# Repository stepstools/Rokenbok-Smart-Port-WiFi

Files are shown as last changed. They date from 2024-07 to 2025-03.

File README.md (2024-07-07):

# Rokenbok Smart Port WiFi Adapter

An ESP32-S3 based system for communicating with the Rokenbok first generation command deck's "Smart Port" over WiFi.

## For More Information

Join the Rokenbok Discord server and check out the "roktronics-projects" channel for more info! - [Invite Link](https://discord.gg/neh6QHN)

## Authors

  - **Stepstools** - *Hardware Design and Firmware Developer* -
    [stepstools](https://github.com/stepstools)

See also the list of
[contributors](https://github.com/stepstools/Rokenbok-Smart-Port-WiFi/contributors)
who participated in this project.

## Acknowledgments

  - OTA Update Code Shamelessly Stolen From: https://github.com/Jeija/esp32-softap-ota/tree/master/main

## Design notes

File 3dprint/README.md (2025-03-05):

## 3D printable case FreeCAD source file and STLs for the SmartPort adapter

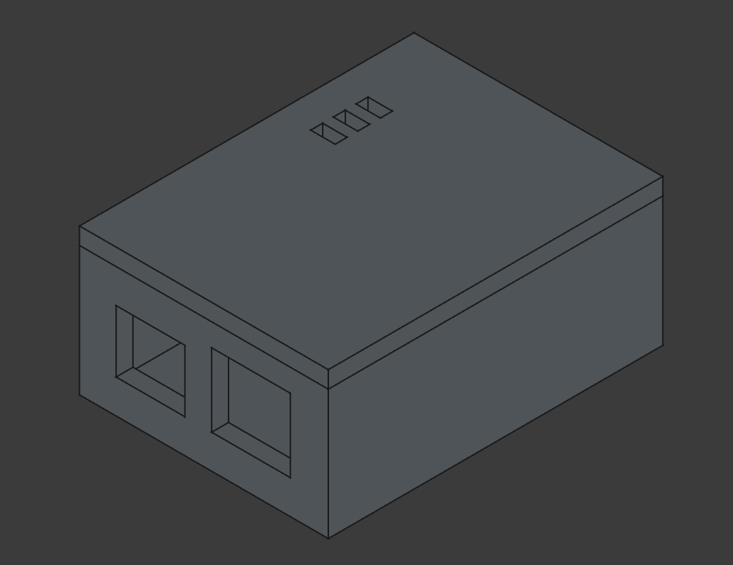
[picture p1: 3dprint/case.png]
Image of case


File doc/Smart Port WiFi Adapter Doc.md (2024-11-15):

# Rokenbok Smart Port WiFi Adapter Documentation

## Required Equipment

 1. Rokenbok WiFi Smart Port Adapter (SPA)
 2. USB A Male to USB B Male Cable (Printer Cable)
 3. Male to Male Mini-DIN-6 Cable (PS/2 Keyboard/Mouse Cable)

## Getting Started

 1. Power up the adapter by connecting it to a USB power source using the USB A to USB B cable.  You will see the red "PWR" LED illuminate.
 2. The blue "WIFI" LED on the device will begin blinking slowly.  This indicates that the device is in the WiFi provisioning mode and is functioning as a wireless access point.
 3. Using a WiFi enabled device, connect to the "Smart-Port-Provisioning" network.  The password is also "Smart-Port-Provisioning".
 4. Using a web browser, navigate to "1.2.3.4" to access the adapter's provisioning web server.  Follow the instructions on the page to input the SSID, password, and static IP information for your local network.
	 - WARNING: DO NOT set your admin password to a password you use for anything else.  This password is sent over the internet unencrypted if you use it later!  Safe enough for this little toy, but don't compromise your important passwords!
	 - Note: The IP address information is required to set up a known "static IP" address for your adapter.  This way your router's DHCP server won't change the adapter's IP and leave you unable to connect.
 5. After double checking all of your info, click the "Submit" button.  You will see the device restart.  If the WiFi LED goes solid blue, this means that it has successfully connected to your network.
	 - If the WiFi LED rapidbly blinks this means that it cannot connect to your network.  It will eventually clear your inputted credentials, reboot, and then re-enter provisioning mode.  You can also hold the reset button to re-enter provisioning mode at any time.  Double check your WiFi credentials and try again.
 6. Now connect the adapter to your Gen 1 Rokenbok RC command deck Smart Port using the male to male mini-DIN-6 cable.  It is best to do this while the command deck is off.
 7. Power up the command deck and the "SP" (Smart Port) LED on your adapter should turn green.
	 - If the SP LED does not illuminate, check your connection.  Excessively long cables (greater than 6 feet) may not work.
 8. On a device connected to your network (WiFi or ethernet), open a web browser and navigate to the static IP address that you selected.  You are now ready to use the device!
 9. You can control Rokenbok vehicles using either your keyboard or a standard layout gamepad.  Non standard gamepads will require additional software to emulate a standard gamepad.  See the "Help" page for more information about keyboard controls.  Gamepads should be automatically detected when you press a button.  The controls are identical to normal Rokenbok, except that start and select are used to change your vehicle selection.

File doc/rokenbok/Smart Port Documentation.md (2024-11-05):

# Rokenbok Smart Port Documentation

## Introduction

The first generation Rokenbok RC command deck featured an expansion port known as the “Smart Port.” Patent documents indicate that the company had intended to develop peripherals capable of interfacing through the port. Unfortunately these plans never materialized and the port was removed from subsequent generations of the RC command deck. More than two decades later the functionality of the port is now understood and peripherals have been develop to interface with the command deck.

## Smart Port Basic Functionality

The command deck actually has four virtual controllers in addition to the four physical controllers that can be plugged into the command deck. The basic purpose of the Smart Port is to manipulate these four virtual controllers. The microcontroller onboard the command deck stores the current vehicle selection value and button states for each of the eight controllers. An external peripheral can use the smart port to manipulate these values directly. As such, the smart port can actually override the physical controllers and manipulate all eight controllers. Additionally, Rokenbok had plans to create controllers that could select up to 16 vehicles. While this controller never materialized, the functionality existed on the command deck microcontroller and can be exploited by the smart port.

## The Smart Port Connector

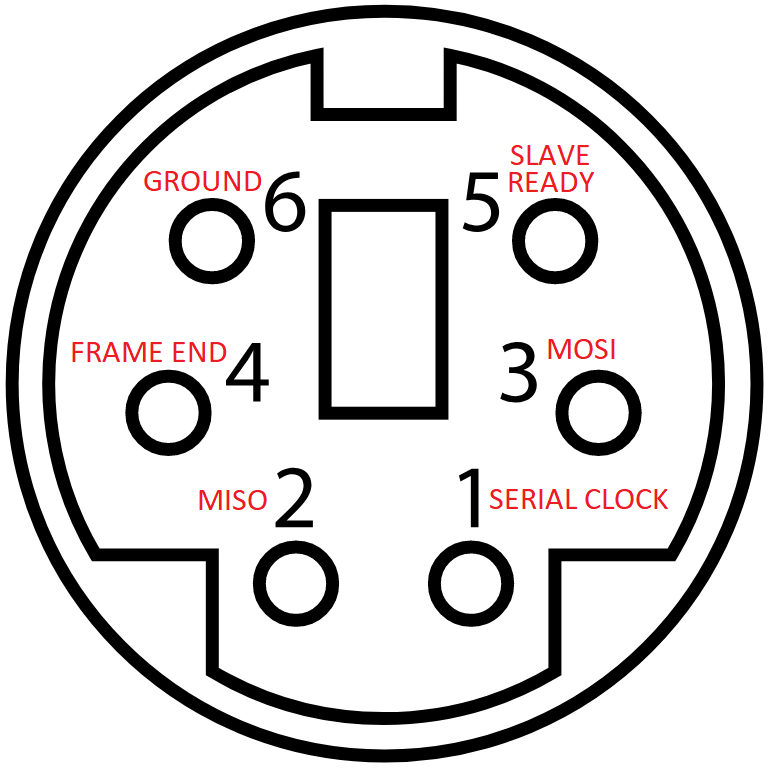
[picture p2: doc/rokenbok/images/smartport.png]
Smartport diagram


The Smart Port connector on the command deck closely resembles the PS/2 connector found on older mice and keyboards. While the connector is the same (female Mini DIN-6), the pinouts and communication protocols are entirely different. The protocol is similar to SPI but with two extra pins. In the serial communication the command deck functions as the master and the peripheral is the slave. Pin 1 is the serial clock provided by the command deck. Pin 2 is the Master In Slave Out data line provided by the peripheral. Pin 3 is the Master Out Slave In data line provided by the command deck. Pins 1, 2, and 3 are all 5V and active high. Pin 4 is known as the “frame end” pin. It is normally driven high at 12V by the command deck, but is pulled low at the end of each byte transmission by the command deck. It’s really not necessary in the serial communication – normal SPI serial communication does not use this. The slave should know when all 8 bits have been sent because of the clock. The reason why Rokenbok made this line 12V was to provide the peripheral with a source of power. The line is only pulled low less than 5% of the time, so a capacitor can be used to smooth that dip to provide continuous power to the peripheral through a regulator. Pin 5 is the “slave ready” pin. Again, most SPI communication protocols don’t use something like this. However, this line is required to make the connection work. The command deck weakly pulls the line up to 5V. When the peripheral is ready to receive the next byte it simply drives the line low. Once it has received the byte it sets the line back to high while it processes the new data. Pin 6 is simply a common ground between the master and slave.

## Serial Communication

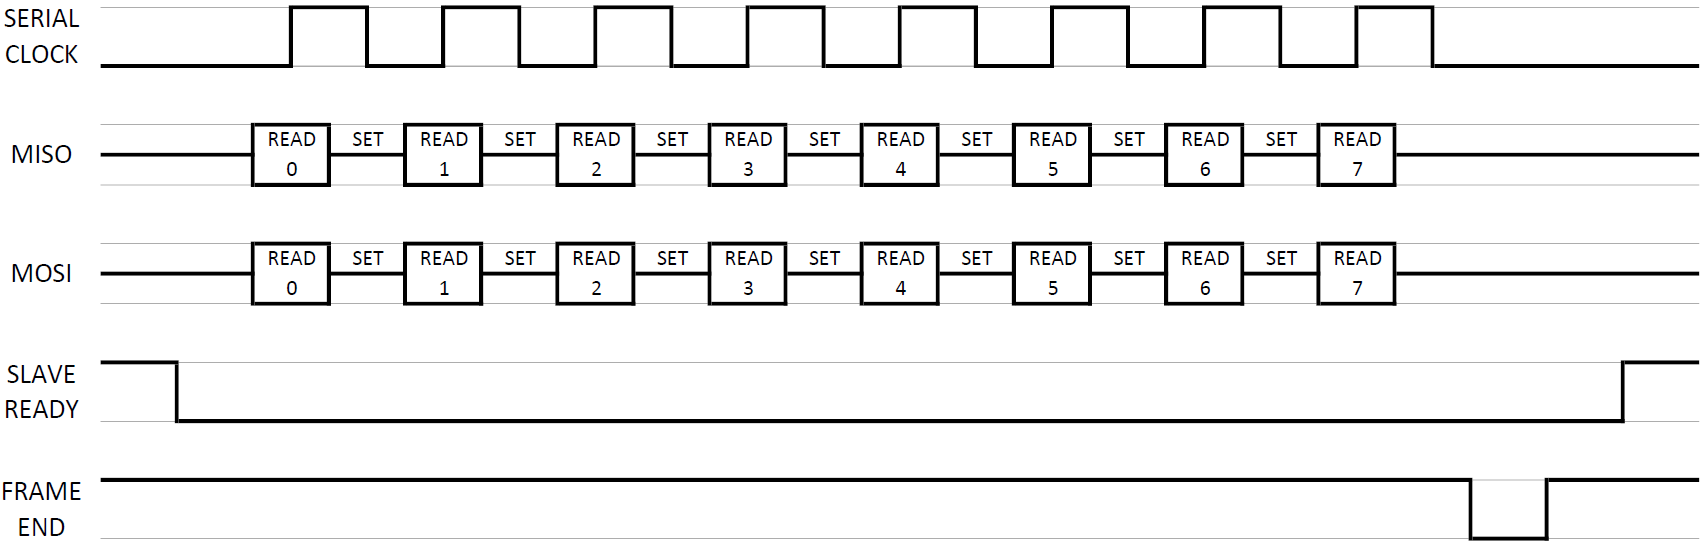
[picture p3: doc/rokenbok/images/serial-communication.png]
Serial communication


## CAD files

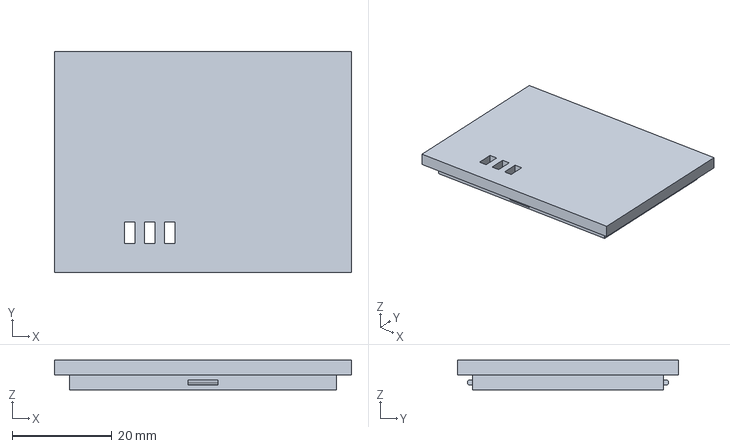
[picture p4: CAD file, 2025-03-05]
3dprint/smartportcase.FCStd
59.5 x 44.3 x 6.00 mm

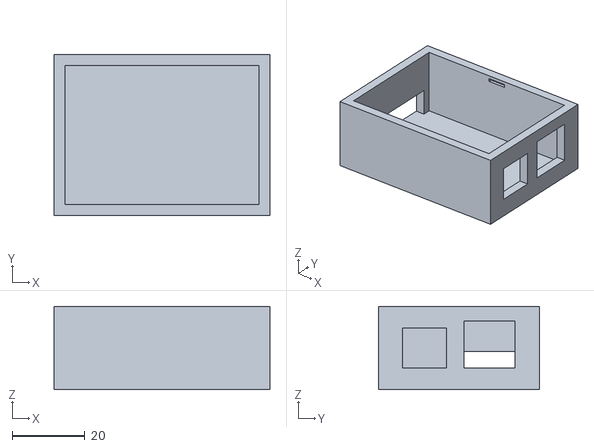
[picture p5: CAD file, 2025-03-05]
3dprint/body.stl
59.5 x 44.2 x 23.0

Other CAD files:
3dprint/lid.stl

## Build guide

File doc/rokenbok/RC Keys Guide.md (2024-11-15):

# Rokenbok RC Select Keys

## Overview

There are three main components of the selector keys used with the radio controlled Rokenbok system:

1. The LED and metal contacts on the side of the key.
    - Current flows from one contact, through the LED (emitting some photons along the way), and back to ground at the other contact.

2. The two central ridges on the back of the key.
    - The metal bars connecting these ridges are used as a sort of switch that closes the connection between the corresponding metal buttons inside the key socket on the vehicle. This is how the machine knows when a key has been inserted, removed, or pressed down to wake the vehicle.

3. The remaining four ridges (or lack thereof) on the back of the key.
    - These ridges are used as binary code to identify which key has been inserted into the vehicle. This is where the magic happens…

## Binary and Rokenbok

If you know absolutely nothing about binary numbering, I recommend you watch some videos online. You’ll be able to pick it up pretty quickly. As mentioned before, the 4 outer ridges on the RC keys are each one bit. This means that there are 2<sup>4</sup> possible combinations for the ridges and therefore 16 unique control keys. In case you were curious, 4 bits is half of a byte and is therefore referred to as a _nibble_. For reference, here are the equivalent binary, hex, and decimal values for each possible number in a nibble:

| **Binary** | **Hexadecimal** | **Decimal** | **Key Number** |
| --- | --- | --- | --- |
| 0000 | 0 | 0 | 1 |
| 0001 | 1 | 1 | 2 |
| 0010 | 2 | 2 | 3 |
| 0011 | 3 | 3 | 4 |
| 0100 | 4 | 4 | 5 |
| 0101 | 5 | 5 | 6 |
| 0110 | 6 | 6 | 7 |
| 0111 | 7 | 7 | 8 |
| 1000 | 8 | 8 | 9 |
| 1001 | 9 | 9 | 10  |
| 1010 | A | 10  | 11  |
| 1011 | B | 11  | 12  |
| 1100 | C | 12  | 13  |
| 1101 | D | 13  | 14  |
| 1110 | E | 14  | 15  |
| 1111 | F | 15  | No Select |

Okay, so what do nibbles have to do with Rokenbok? I’m glad you asked. When you insert a key into the socket of a vehicle, the 4 outer ridges either depress one of the metal switches or they don’t. If there is a ridge, the switch is depressed. If there isn’t a ridge, the switch is not depressed. Rokenbok decided to be a bit counterintuitive with how they set up this numbering system, so it takes some explaining:

- Because most people don’t start counting at zero, the actual key number is the binary number plus one (this can be seen in the previous table).

  - Also, one value needed to be assigned as a “no selection” value, so 1111 was chosen for this. If the smart port is used to force the selection of a physical controller to decimal number 15, the selection LEDs will spin in a circle as if the controller was asleep.

- The presence of a ridge (and therefore a pressed switch) is a binary zero. The absence of a ridge (and therefore an unpressed switch) is a binary one.

  - This is clearly seen on the number 1 key, which has all four ridges present, therefore corresponding to binary number 0000.

- The ridges are not in any specific order. The pictures below show the order of the ridges starting from bit 0 (all the way right in a nibble) to bit 3 (all the way left in a nibble).

  - This can be clearly seen in the number 8 key, which only has ridge 3 remaining, corresponding to binary number 0111.

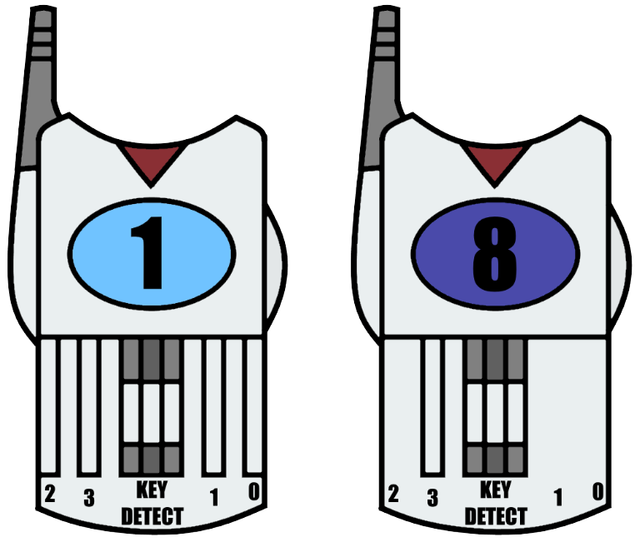
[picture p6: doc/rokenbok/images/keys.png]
Rokenbok key diagram


## Controlling More Than Eight Vehicles

Rokenbok decided to be boring and only use 8 of the 16 possible keys. They actually described potentially making controllers capable of selecting 16 vehicles in their patent requests, but they never got around to doing it. However, the smart port is more than capable of controlling these extra vehicles! Unfortunately, number 16 is unavailable due to its use as the “no select” code, but we can still get numbers 9-15! If you’ve been following along, you’ll know that control keys 1-8 all have ridge three present. Now, if we remove that ridge, suddenly bit number 3 changes from a zero to a one. A one in binary position three is equal to 8, so you’ve just added 8 to the value of the key! Number 1 becomes 9, 2 becomes 10, etc. This checks out with the table above if you flip the leftmost bit of any number. Don’t forget that there’s no need to hack up your number 8 key since 16 isn’t a valid selection.

~~Caveat: I haven’t actually done this. However, I had a friend help me and depress the switch for bit zero on a vehicle using a small screwdriver while I used a piece of wire to simulate the central ridges turning on the vehicle. I was successfully able to control the vehicle as key number 15 (binary 1110, only ridge zero present). It might be possible that only certain vehicles work with this hack. My worst case scenario guess is that only older vehicles work with this. It’s possible that newer vehicles lost this functionality once Rokenbok ditched the smart port and decided not to make 16 selection controllers. Of course, my best case scenario guess is that they all work! Only one way to find out…~~

Update: Multiple people have successfully created keys 9-15 by physically removing the third ridge from keys 1-7.  Key 8 cannot be turned into key 16.

Guide By: Stepstools, the Smart Port Dude

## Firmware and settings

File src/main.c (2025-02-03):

// ASCII Art: https://www.patorjk.com/software/taag/ ("Big" Font)
// OTA Update Code Shamelessly Stolen From: https://github.com/Jeija/esp32-softap-ota/tree/master/main

#include <stdio.h>
#include <string.h>
#include "freertos/FreeRTOS.h"
#include "freertos/task.h"
#include "freertos/event_groups.h"
#include "nvs_flash.h"
#include <esp_system.h>
#include "esp_wifi.h"
#include "esp_event.h"
#include "esp_log.h"
#include "esp_http_server.h"
#include "esp_http_client.h"
#include "esp_netif.h"
#include "lwip/sockets.h"
#include "driver/gpio.h"
#include "driver/gpio_filter.h"
#include "driver/spi_slave.h"
#include "esp_timer.h"
#include "esp_ota_ops.h"

#define MIN(a, b) (((a) < (b)) ? (a) : (b))
#define MAX(a, b) (((a) > (b)) ? (a) : (b))

// OTA Firmware Update URL
#define OTA_URL "https://raw.githubusercontent.com/stepstools/Rokenbok-Smart-Port-WiFi/refs/heads/main/firmware/ota_firmware.bin"

// WiFi Defines
#define AP_SSID "Smart-Port-Provisioning"
#define AP_PASSWORD "Smart-Port-Provisioning"
#define MAX_WIFI_SSID_LEN 32
#define MAX_WIFI_PASSWORD_LEN 64
#define WIFI_CONNECT_ATTEMPTS 20

// Smart Port Master Bytes
#define NULL_CMD 0x00
#define BCAST_TPADS 0xc0
#define BCAST_SELECT 0xC1
#define BCAST_END 0xC2
#define EDIT_TPADS 0xC3
#define EDIT_SELECT 0xC4
#define EDIT_END 0xC5
#define PRESYNC 0xC6
#define MASTER_SYNC 0xC7
#define READ_ATTRIB 0xC8
#define MASTER_NO_INS 0xC9
#define MASTER_ASK_INS 0xCA
#define READ_REPLY 0xCB
#define READ_NO_SEL_TIMEOUT 0xCC
#define NO_RADIO_PKT 0xCD
#define HAVE_RADIO_PKT 0xCE

// Smart Port Slave Bytes
#define NULL_CMD 0x00
#define VERIFY_EDIT 0x80
#define SLAVE_SYNC 0x81
#define SLAVE_NO_INS 0x82
#define SLAVE_WAIT_INS 0x83
#define PACKET_INJECT_ATTRIB_BYTE 0x2D // Packet Injection
#define ENABLE_ATTRIB_BYTE 0x0D // No Packet Injection
#define DISABLE_ATTRIB_BYTE 0x00
#define NO_SEL_TIMEOUT 0x00 // 1 = Controller Never Times Out, 0 = Normal V4|V3|V2|V1|P4|P3|P2|P1

// Series Logic Defines
#define NO_SERIES 0
#define SYNC_SERIES 1
#define EDIT_TPADS_SERIES 2
#define EDIT_SELECT_SERIES 3
#define PKT_INJECT_SERIES 4

// GPIO Defines
#define GPIO_RESET 0
#define GPIO_MOSI 11
#define GPIO_MISO 13
#define GPIO_SCLK 12
#define GPIO_FE 9
#define GPIO_SR 21
#define GPIO_WIFI_LED 18
#define GPIO_SP_LED 17

//  __      __     _____  _____          ____  _      ______  _____   //
//  \ \    / /\   |  __ \|_   _|   /\   |  _ \| |    |  ____|/ ____|  //
//   \ \  / /  \  | |__) | | |    /  \  | |_) | |    | |__  | (___    //
//    \ \/ / /\ \ |  _  /  | |   / /\ \ |  _ <| |    |  __|  \___ \   //
//     \  / ____ \| | \ \ _| |_ / ____ \| |_) | |____| |____ ____) |  //
//      \/_/    \_\_|  \_\_____/_/    \_\____/|______|______|_____/   //

// Global Variables
char nvs_admin_password[33] = "NULL";
char nvs_vehicle_names[15][21] = {"No Data", "No Data", "No Data", "No Data", "No Data", "No Data", "No Data", "No Data", "No Data", "No Data", "No Data", "No Data", "No Data", "No Data", "No Data"};
char control_key_user_names[256][17] = {0};

// Rokenbok Control Logic Variables
uint8_t timeouts[12] = {false, false, false, false, false, false, false, false, false, false, false, false}; // V1, V2, V3, V4, P1, P2, P3, P4, D1, D2, D3, D4
uint8_t enable_control[12] = {false, false, false, false, false, false, false, false, false, false, false, false}; // V1, V2, V3, V4, P1, P2, P3, P4, D1, D2, D3, D4 // FALSE = Normal, TRUE = SP Controlled
//uint8_t control_keys[12] = {0x19, 0x20, 0x30, 0x40, 0x50, 0x60, 0x70, 0x80, 0x00, 0x00, 0x00, 0x00}; // V1, V2, V3, V4, P1, P2, P3, P4, D1, D2, D3, D4
uint8_t control_keys[12] = {0x00, 0x00, 0x00, 0x00, 0x00, 0x00, 0x00, 0x00, 0x00, 0x00, 0x00, 0x00}; // V1, V2, V3, V4, P1, P2, P3, P4, D1, D2, D3, D4
uint8_t next_control_key = 2; // 0 = Unused, 1 = Physical Controller Plugged In

uint8_t next_dpi_index = 0;

uint8_t selects[12] = {0x0F, 0x0F, 0x0F, 0x0F, 0x0F, 0x0F, 0x0F, 0x0F, 0x0F, 0x0F, 0x0F, 0x0F}; // V1, V2, V3, V4, P1, P2, P3, P4, D1, D2, D3, D4

uint8_t share_mode = true;
uint8_t is16sel_mode = true;
uint8_t controller_timeout = 10;

uint8_t enabled_controllers = 0b11111111; // V4|V3|V2|V1|P4|P3|P2|P1 // 0 = Enabled, 1 = Disabled
uint8_t sp_a = 0x00;                      // V4|V3|V2|V1|P4|P3|P2|P1
uint8_t sp_b = 0x00;
uint8_t sp_x = 0x00;
uint8_t sp_y = 0x00;
uint8_t sp_up = 0x00;
uint8_t sp_down = 0x00;
uint8_t sp_right = 0x00;
uint8_t sp_left = 0x00;
uint8_t sp_rt = 0x00;
// uint8_t sp_sel_button = 0x00;
// uint8_t sp_lt = 0x00;
// uint8_t sp_share = 0x00;
// uint8_t sp_is16SEL = 0x00;
uint8_t sp_priority_byte = 0x00;

uint8_t dpi_a[4] = {false, false, false, false};
uint8_t dpi_b[4] = {false, false, false, false};
uint8_t dpi_x[4] = {false, false, false, false};
uint8_t dpi_y[4] = {false, false, false, false};
uint8_t dpi_up[4] = {false, false, false, false};
uint8_t dpi_down[4] = {false, false, false, false};
uint8_t dpi_left[4] = {false, false, false, false};
uint8_t dpi_right[4] = {false, false, false, false};
uint8_t dpi_rt[4] = {false, false, false, false};

uint8_t sp_status = 0;

uint8_t spi_current_series = 0;
uint8_t spi_series_count = 0;

// Variables and Structs for WiFi Event Management
EventGroupHandle_t wifi_event_group;
uint8_t WIFI_CONNECTED_BIT = BIT0;
uint8_t connection_attempts = 0;
uint8_t wifi_led_status = false;

// Timer Handle Definitions
esp_timer_handle_t sync_timer;
esp_timer_handle_t timeout_timer;
esp_timer_handle_t post_timeout_timer;
esp_timer_handle_t reset_button_timer;
esp_timer_handle_t wifi_led_timer;

//   _    _ ______ _      _____  ______ _____    //
//  | |  | |  ____| |    |  __ \|  ____|  __ \   //
//  | |__| | |__  | |    | |__) | |__  | |__) |  //
//  |  __  |  __| | |    |  ___/|  __| |  _  /   //
//  | |  | | |____| |____| |    | |____| | \ \   //
//  |_|  |_|______|______|_|    |______|_|  \_\  //

/// @brief Converts all + to spaces and converts percent encoded values within a string.
/// @param string String to process.
void convert_percent_encoded(char *string) {
    char *src = string;
    char *dst = string;
    while (*src) {
        if (*src == '+') {
            *dst++ = ' '; // Convert '+' to space
            src++;
        } else if (src[0] == '%' && isxdigit((unsigned char)src[1]) && isxdigit((unsigned char)src[2])) {
            int value;
            sscanf(src + 1, "%2x", &value); // Convert hex digits to a character
            *dst++ = (char)value;
            src += 3; // Move past "%XX"
        } else {
            *dst++ = *src++; // Copy regular characters
        }
    }
    *dst = '\0'; // Null-terminate the result string
}

/// @brief Helper function to determine if an array contains a value.
/// @param array The array to be checked.
/// @param size The size of the array.
/// @param value The value being looked for.
/// @return true or false boolean value.
bool contains(uint8_t array[], size_t size, uint8_t value)
{
    for (size_t i = 0; i < size; i++)
    {
        if (array[i] == value)
        {
            return true;
        }
    }
    return false;
}

//  __          ________ ____   _____ ______ _______      ________ _____    //
//  \ \        / /  ____|  _ \ / ____|  ____|  __ \ \    / /  ____|  __ \   //
//   \ \  /\  / /| |__  | |_) | (___ | |__  | |__) \ \  / /| |__  | |__) |  //
//    \ \/  \/ / |  __| |  _ < \___ \|  __| |  _  / \ \/ / |  __| |  _  /   //
//     \  /\  /  | |____| |_) |____) | |____| | \ \  \  /  | |____| | \ \   //
//      \/  \/   |______|____/|_____/|______|_|  \_\  \/   |______|_|  \_\  //

/// @brief HTTP Client Event Handler
/// @param evt Event to handle.
/// @return Error Code
esp_err_t http_client_event_handler(esp_http_client_event_t *evt) {
    // switch(evt->event_id) {
    //     case HTTP_EVENT_ERROR:
    //         ESP_LOGI("HTTP CLIENT", "HTTP_EVENT_ERROR");
    //         break;
    //     case HTTP_EVENT_ON_CONNECTED:
    //         ESP_LOGI("HTTP CLIENT", "HTTP_EVENT_ON_CONNECTED");
    //         break;
    //     case HTTP_EVENT_HEADER_SENT:
    //         ESP_LOGI("HTTP CLIENT", "HTTP_EVENT_HEADER_SENT");
    //         break;
    //     case HTTP_EVENT_ON_HEADER:
    //         ESP_LOGI("HTTP CLIENT", "HTTP_EVENT_ON_HEADER, key=%s, value=%s", evt->header_key, evt->header_value);
    //         break;
    //     case HTTP_EVENT_ON_DATA:
    //         ESP_LOGI("HTTP CLIENT", "HTTP_EVENT_ON_DATA, len=%d", evt->data_len);
    //         break;
    //     case HTTP_EVENT_ON_FINISH:
    //         ESP_LOGI("HTTP CLIENT", "HTTP_EVENT_ON_FINISH");
    //         break;
    //     case HTTP_EVENT_DISCONNECTED:
    //         ESP_LOGI("HTTP CLIENT", "HTTP_EVENT_DISCONNECTED");
    //         break;
    //     case HTTP_EVENT_REDIRECT:
    //         ESP_LOGI("HTTP CLIENT", "HTTP_EVENT_REDIRECT");
    //         break;
    // }
    return ESP_OK;
}

/// @brief Interprets received control codes and assigns controllers to control keys.
/// @param control_code Specified Action Code (Press A, Unpress A, etc.)
/// @param control_key Control Key For the Source Gamepad/Keyboard/Mobile
/// @return void
static uint8_t IRAM_ATTR handle_control_bytes(uint8_t control_code, uint8_t control_key, uint8_t requested_vehicle)
{
    uint8_t controller_index = 255;
    for (uint8_t i = 0; i < 12; i++) // Search For Control Key In Virtual, Physical, and Direct Packet Injection (DPI)
    {
        if (control_keys[i] == control_key) // Control Key Found
        {
            controller_index = i;
            // ESP_LOGI("SP", "CONTROL KEY %i ALREADY ASSIGNED TO CONTROLLER %i", control_key, i);
            break;
        }
    }

    if (controller_index == 255) // Control Key Not Found
    {
        for (uint8_t i = 0; i < 12; i++) // Search For Unused Virtual or Physical Controller
        {
            if (control_keys[i] == 0) // Controller Not Currently Used
            {
                controller_index = i;
                control_keys[i] = control_key;
                enable_control[i] = true;
                if (controller_index < 8) // Only Do This Step For Virtual and Physical Controllers
                {
                    enabled_controllers &= ~(0b00000001 << ((i + 4) % 8));
                }
                // ESP_LOGI("SP", "CONTROL KEY %i NOW ASSIGNED TO CONTROLLER %i", control_key, i);
                break;
            }
        }
    }

    if (controller_index == 255) // No Empty Spots Available
    {
        //ESP_LOGI("SP", "NO AVAILABLE CONTROLLERS TO ASSIGN");
        return 0xFF;
    }

    timeouts[controller_index] = true; // Indicate That Controller Was Used During Timeout Cycle

    uint8_t select_changed = false;
    if (selects[controller_index] != requested_vehicle)
    { // If the requested vehicle is different from the stored value...
        select_changed = true;
        if ((share_mode) || (requested_vehicle == 15))
        { // Just give the assignment if share mode is on or no_select is requested.
            selects[controller_index] = requested_vehicle;
        }
        else
        { 
            uint8_t new_vehicle = requested_vehicle;
            uint8_t max_value = (is16sel_mode ? 14 : 7);
            
            if (new_vehicle == (selects[controller_index] + 1) % (max_value + 1))
            { // Detecting if the value was incremented.
                while (contains(selects, 8, new_vehicle)) {
                    new_vehicle = (new_vehicle + 1) % (max_value + 1);
                }
            }
            else //if (new_vehicle == (selects[controller_index] - 1 + max_value + 1) % (max_value + 1))
            { // Detecting if the value was decremented.
                while (contains(selects, 8, new_vehicle)) {
                    new_vehicle = (new_vehicle == 0) ? max_value : (new_vehicle - 1);
                }
            }
            selects[controller_index] = new_vehicle;
        }
    }

    if (controller_index < 8) // Virtual or Physical Controllers
    {
        uint8_t bitwise_index = (controller_index + 4) % 8; // Convert V1-4, P1-4 Array Index to V4|V3|V2|V1|P4|P3|P2|P1 Bitwise
        switch (control_code)
        {
        // PRESS CONTROL CODES
        case 0x00:
            sp_a |= (0b00000001 << bitwise_index);
            sp_priority_byte |= (0b00000001 << bitwise_index);
            break;

        case 0x01:
            sp_b |= (0b00000001 << bitwise_index);
            sp_priority_byte |= (0b00000001 << bitwise_index);
            break;

        case 0x02:
            sp_x |= (0b00000001 << bitwise_index);
            sp_priority_byte |= (0b00000001 << bitwise_index);
            break;

        case 0x03:
            sp_y |= (0b00000001 << bitwise_index);
            sp_priority_byte |= (0b00000001 << bitwise_index);
            break;

        case 0x04:
            sp_up |= (0b00000001 << bitwise_index);
            sp_priority_byte |= (0b00000001 << bitwise_index);
            break;

        case 0x05:
            sp_down |= (0b00000001 << bitwise_index);
            sp_priority_byte |= (0b00000001 << bitwise_index);
            break;

        case 0x06:
            sp_left |= (0b00000001 << bitwise_index);
            sp_priority_byte |= (0b00000001 << bitwise_index);
            break;

        case 0x07:
            sp_right |= (0b00000001 << bitwise_index);
            sp_priority_byte |= (0b00000001 << bitwise_index);
            break;

        case 0x08:
            sp_rt |= (0b00000001 << bitwise_index);
            sp_priority_byte |= (0b00000001 << bitwise_index);
            break;

        // UNPRESS CONTROL CODES
        case 0x10:
            sp_a &= ~(0b00000001 << bitwise_index);
            sp_priority_byte |= (0b00000001 << bitwise_index);
            break;

        case 0x11:
            sp_b &= ~(0b00000001 << bitwise_index);
            sp_priority_byte |= (0b00000001 << bitwise_index);
            break;

        case 0x12:
            sp_x &= ~(0b00000001 << bitwise_index);
            sp_priority_byte |= (0b00000001 << bitwise_index);
            break;

        case 0x13:
            sp_y &= ~(0b00000001 << bitwise_index);
            sp_priority_byte |= (0b00000001 << bitwise_index);
            break;

        case 0x14:
            sp_up &= ~(0b00000001 << bitwise_index);
            sp_priority_byte |= (0b00000001 << bitwise_index);
            break;

        case 0x15:
            sp_down &= ~(0b00000001 << bitwise_index);
            sp_priority_byte |= (0b00000001 << bitwise_index);
            break;

        case 0x16:
            sp_left &= ~(0b00000001 << bitwise_index);
            sp_priority_byte |= (0b00000001 << bitwise_index);
            break;

        case 0x17:
            sp_right &= ~(0b00000001 << bitwise_index);
            sp_priority_byte |= (0b00000001 << bitwise_index);
            break;

        case 0x18:
            sp_rt &= ~(0b00000001 << bitwise_index);
            sp_priority_byte |= (0b00000001 << bitwise_index);
            break;

        case 0x19: // Unpress All
            sp_a &= ~(0b00000001 << bitwise_index);
            sp_b &= ~(0b00000001 << bitwise_index);
            sp_x &= ~(0b00000001 << bitwise_index);
            sp_y &= ~(0b00000001 << bitwise_index);
            sp_up &= ~(0b00000001 << bitwise_index);
            sp_down &= ~(0b00000001 << bitwise_index);
            sp_left &= ~(0b00000001 << bitwise_index);
            sp_right &= ~(0b00000001 << bitwise_index);
            sp_rt &= ~(0b00000001 << bitwise_index);
            sp_priority_byte |= (0b00000001 << bitwise_index);
            break;

        case 0x1A: // Release Controller
            sp_a &= ~(0b00000001 << bitwise_index);
            sp_b &= ~(0b00000001 << bitwise_index);
            sp_x &= ~(0b00000001 << bitwise_index);
            sp_y &= ~(0b00000001 << bitwise_index);
            sp_up &= ~(0b00000001 << bitwise_index);
            sp_down &= ~(0b00000001 << bitwise_index);
            sp_left &= ~(0b00000001 << bitwise_index);
            sp_right &= ~(0b00000001 << bitwise_index);
            sp_rt &= ~(0b00000001 << bitwise_index);
            sp_priority_byte |= (0b00000001 << bitwise_index);

            selects[controller_index] = 15;
            select_changed = true;

            timeouts[controller_index] = false;
            control_keys[controller_index] = 0;

            esp_timer_start_once(post_timeout_timer, 0.1 * 1000000); // 0.1 Second Interval
            break;

        // UTILITY CONTROL CODES
        // case 0x40: // Soft Reset
        //     enable_control[0] = false;
        //     enable_control[1] = false;
        //     enable_control[2] = false;
        //     enable_control[3] = false;
        //     enable_control[4] = false;
        //     enable_control[5] = false;
        //     enable_control[6] = false;
        //     enable_control[7] = false;

        //     enabled_controllers = 0xFF;

        //     selects[0] = 0x0F;
        //     selects[1] = 0x0F;
        //     selects[2] = 0x0F;
        //     selects[3] = 0x0F;
        //     selects[4] = 0x0F;
        //     selects[5] = 0x0F;
        //     selects[6] = 0x0F;
        //     selects[7] = 0x0F;

        //     sp_a = 0x00;
        //     sp_b = 0x00;
        //     sp_x = 0x00;
        //     sp_y = 0x00;
        //     sp_up = 0x00;
        //     sp_down = 0x00;
        //     sp_right = 0x00;
        //     sp_left = 0x00;
        //     sp_rt = 0x00;

        //     sp_priority_byte = 0xFF;

        //     vTaskDelay(pdMS_TO_TICKS(1000));
        //     break;
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
void app_main(void)
{
    // Mark Current OTA App As Valid
    const esp_partition_t *partition = esp_ota_get_running_partition();
    printf("Currently Running Partition: %s\r\n", partition->label);

    esp_ota_img_states_t ota_state;
    if (esp_ota_get_state_partition(partition, &ota_state) == ESP_OK)
    {
        if (ota_state == ESP_OTA_IMG_PENDING_VERIFY)
        {
            esp_ota_mark_app_valid_cancel_rollback();
        }
    }

    // Initialize User Names for Control Keys 0 and 1
    snprintf(control_key_user_names[0], 17, "No User");
    snprintf(control_key_user_names[1], 17, "Plugged In");

    // Setup GPIO Pins and Interrupts
    gpio_reset_pin(GPIO_SR);
    gpio_set_direction(GPIO_SR, GPIO_MODE_OUTPUT);
    gpio_set_level(GPIO_SR, 1);

    gpio_reset_pin(GPIO_SP_LED);
    gpio_set_direction(GPIO_SP_LED, GPIO_MODE_OUTPUT);
    gpio_set_level(GPIO_SP_LED, 0);

    gpio_reset_pin(GPIO_WIFI_LED);
    gpio_set_direction(GPIO_WIFI_LED, GPIO_MODE_OUTPUT);
    gpio_set_level(GPIO_WIFI_LED, 0);

    gpio_reset_pin(GPIO_RESET);
    gpio_set_direction(GPIO_RESET, GPIO_MODE_INPUT);
    gpio_set_pull_mode(GPIO_RESET, GPIO_PULLUP_ONLY);

    gpio_reset_pin(GPIO_FE);
    gpio_set_direction(GPIO_FE, GPIO_MODE_INPUT);
    gpio_set_pull_mode(GPIO_FE, GPIO_PULLUP_ONLY);

    // Configure Reset Interrupt
    gpio_intr_enable(GPIO_RESET);
    gpio_set_intr_type(GPIO_RESET, GPIO_INTR_ANYEDGE);
    gpio_install_isr_service(ESP_INTR_FLAG_LEVEL1);
    gpio_isr_handler_add(GPIO_RESET, reset_isr_handler, NULL);

    gpio_pin_glitch_filter_config_t SCLK_config = {
        .clk_src = SOC_ROOT_CLK_INT_RC_SLOW,
        .gpio_num = GPIO_SCLK,
    };
    gpio_glitch_filter_handle_t SCLK_filter;
    gpio_new_pin_glitch_filter(&SCLK_config, &SCLK_filter);
    gpio_glitch_filter_enable(SCLK_filter);

    // Initialize SP Sync Timer
    const esp_timer_create_args_t sync_timer_args = {
        .callback = &sync_timer_callback,
        .name = "sync_timer"};
    esp_timer_create(&sync_timer_args, &sync_timer);
    esp_timer_start_periodic(sync_timer, 0.1 * 1000000); // 0.1 Second Interval

    // Initialize Post Timeout Timer
    const esp_timer_create_args_t post_timeout_timer_args = {
        .callback = &post_timeout_timer_callback,
        .name = "post_timeout_timer"};
    esp_timer_create(&post_timeout_timer_args, &post_timeout_timer);

    // Initialize Reset Button Timer
    const esp_timer_create_args_t reset_button_timer_args = {
        .callback = &reset_button_timer_callback,
        .name = "reset_button_timer"};
    esp_timer_create(&reset_button_timer_args, &reset_button_timer);

    // Initialize WiFi LED Timer
    const esp_timer_create_args_t wifi_led_timer_args = {
        .callback = &wifi_led_timer_callback,
        .name = "wifi_led_timer"};
    esp_timer_create(&wifi_led_timer_args, &wifi_led_timer);

    // Configuration for the SPI bus
    spi_bus_config_t buscfg = {
        .mosi_io_num = GPIO_MOSI,
        .miso_io_num = GPIO_MISO,
        .sclk_io_num = GPIO_SCLK,
        .quadwp_io_num = -1,
        .quadhd_io_num = -1,
    };

    // Configuration for the SPI slave interface
    spi_slave_interface_config_t slvcfg = {
        .mode = 0,
        .spics_io_num = GPIO_FE,
        .queue_size = 1,
        .flags = 0,
        .post_setup_cb = post_setup_callback,
        .post_trans_cb = post_transaction_callback};

    // Initialize the SPI Slave Interface
    spi_slave_initialize(SPI2_HOST, &buscfg, &slvcfg, SPI_DMA_DISABLED);

    // Initialize the SPI Task
    xTaskCreate(&spi_task, "SPI_TASK", 4096, NULL, 1, NULL);

    // Initialize the WiFi event group
    wifi_event_group = xEventGroupCreate();

    // Initialize NVS and check/configure WiFi
    wifi_init_from_nvs();

    // Initialize Controller Timeout Timer (Must Be After wifi_init_from_nvs)
    const esp_timer_create_args_t timeout_timer_args = {
        .callback = &timeout_timer_callback,
        .name = "timeout_timer"};
    esp_timer_create(&timeout_timer_args, &timeout_timer);
    esp_timer_start_periodic(timeout_timer, controller_timeout * 1000000); // controller_timeout Second Interval

    // while (1) {
    //     vTaskDelay(pdMS_TO_TICKS(100));
    // }
}

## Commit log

2024-07-15 Added bank gothic font to all headers.
    [partitions.csv]
2024-09-03 Fixed monorail bug and implemented RT+A and RT+B functionality in one fell swoop!
    [main.c]
2024-09-14 Fixed two minor bugs.
    [main.c]
2024-10-06 Added driver dependency.
2024-10-26 Added reset button restart function. Added WiFi host name.
2024-10-27 Fixed percent encoding issue.
    [main.c]
2024-11-05 Added WiFi LED flash when reset button is held.
2025-02-03 Fixed and improved select wrap around logic.
    [main.c]
2025-03-02 add files for 3d printable case
    [body.stl, lid.stl, smartportcase.FCStd]
2026-11-03 Refactor SP control loop to switch statement & autoformat.
